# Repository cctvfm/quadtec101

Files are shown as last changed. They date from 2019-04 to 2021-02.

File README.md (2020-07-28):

# quadtec101
A Quad Panning Oscillator designed for the Neuztec 4 Festival

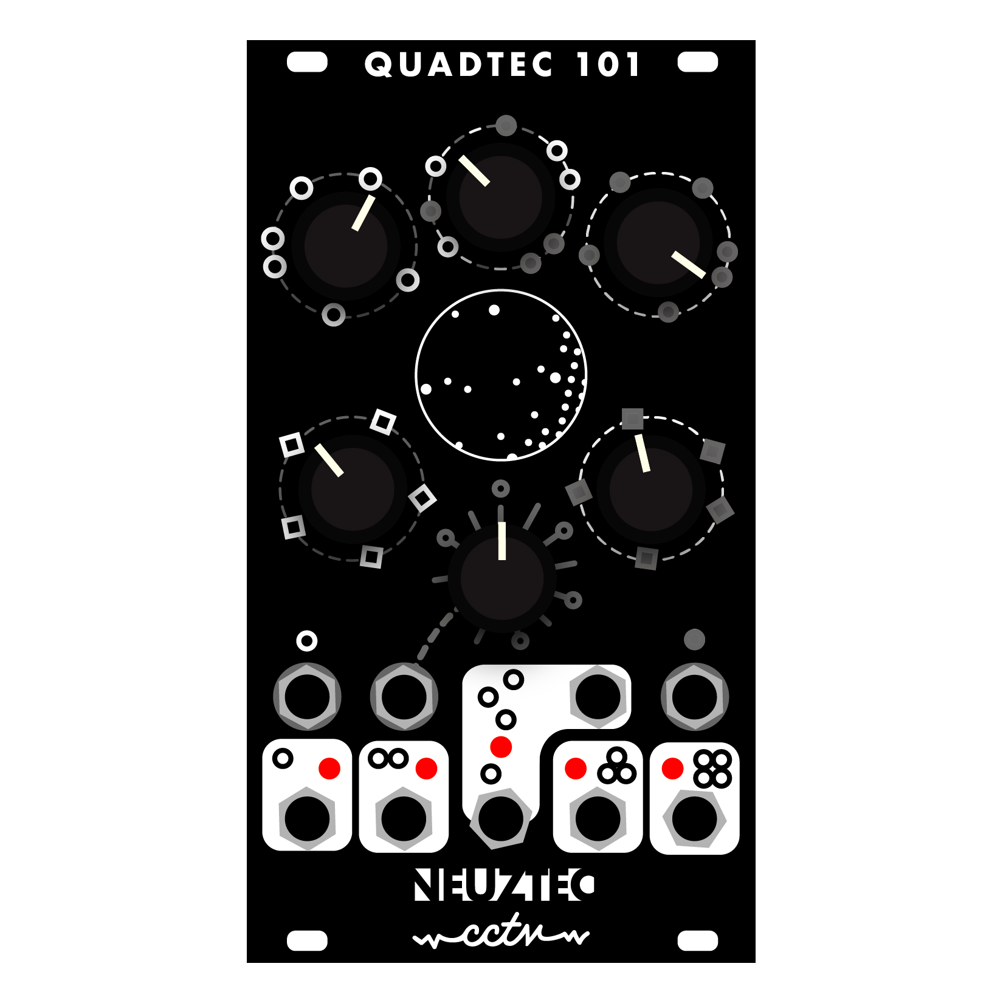
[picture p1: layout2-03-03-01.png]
QUADTEC-101 Render


More info here: [cctv.fm](https://www.cctv.fm/product-page/quadtec-101)

Sign up here: [Neuzlab](http://www.neuztec.ca/neuzlab/)

>QUADTEC-101 A MUSICAL INSTRUMENT FROM THE FUTURE.

>THE GARDEN CITY ELECTRONIC MUSIC COMMUNITY CREATED A TIMEMACHINE USING RARE TELSA BLUEPRINTS AND WENT INTO THE FUTURE TO GATHER DATA OF THE DAY; SEEKING OUT INSTRUMENTS FROM THE CREATIVE YOUTH OF THE FUTURE. UPON RETURNING TO 2019 THEY BROUGHT THOSE IDEAS TO FILIP PIETRUSZEWSKI TO RE-ENGINEER, DESIGN, AND REALIZE THIS FUTURISTIC INSTRUMENT USING MODERN AND ANTIIQUE TOOLS AT HIS MAD SCIENCE LAB AT CAPITAL CITY TRANSISTOR AND VALVE.

# Licensing

CC BY-NC-SA

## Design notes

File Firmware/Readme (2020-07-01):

Firmware is writting in C in MPLAB X IDE v 3.65. Some optimization is used, but it's using the free XC16 compiler.

.hex file can be uploaded through IPE and is ready to go. Make sure to select 'DSPIC30F3013' as the device type.

If you purchased a kit, the processor is pre-programmed and ready to go, no need to do any of this stuff.
V1.0 Released April 24th, 2019

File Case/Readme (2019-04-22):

Front and Sides are lasercut from 3mm Acrylic (plywood would work too)
Batteryholder is 3d printed at 1:1 scale.

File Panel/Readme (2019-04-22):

Panel is designed in Illustrator, and then imported into Eagle. BRD File is found here as well as gerber files where the layers have been 'mirrored' so the batch ID ends up on the bottom.

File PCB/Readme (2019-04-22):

This Folder Contains Eagle 9.12 SCH and BRD files, as well as gerbers ready to be sent out for manufacture.

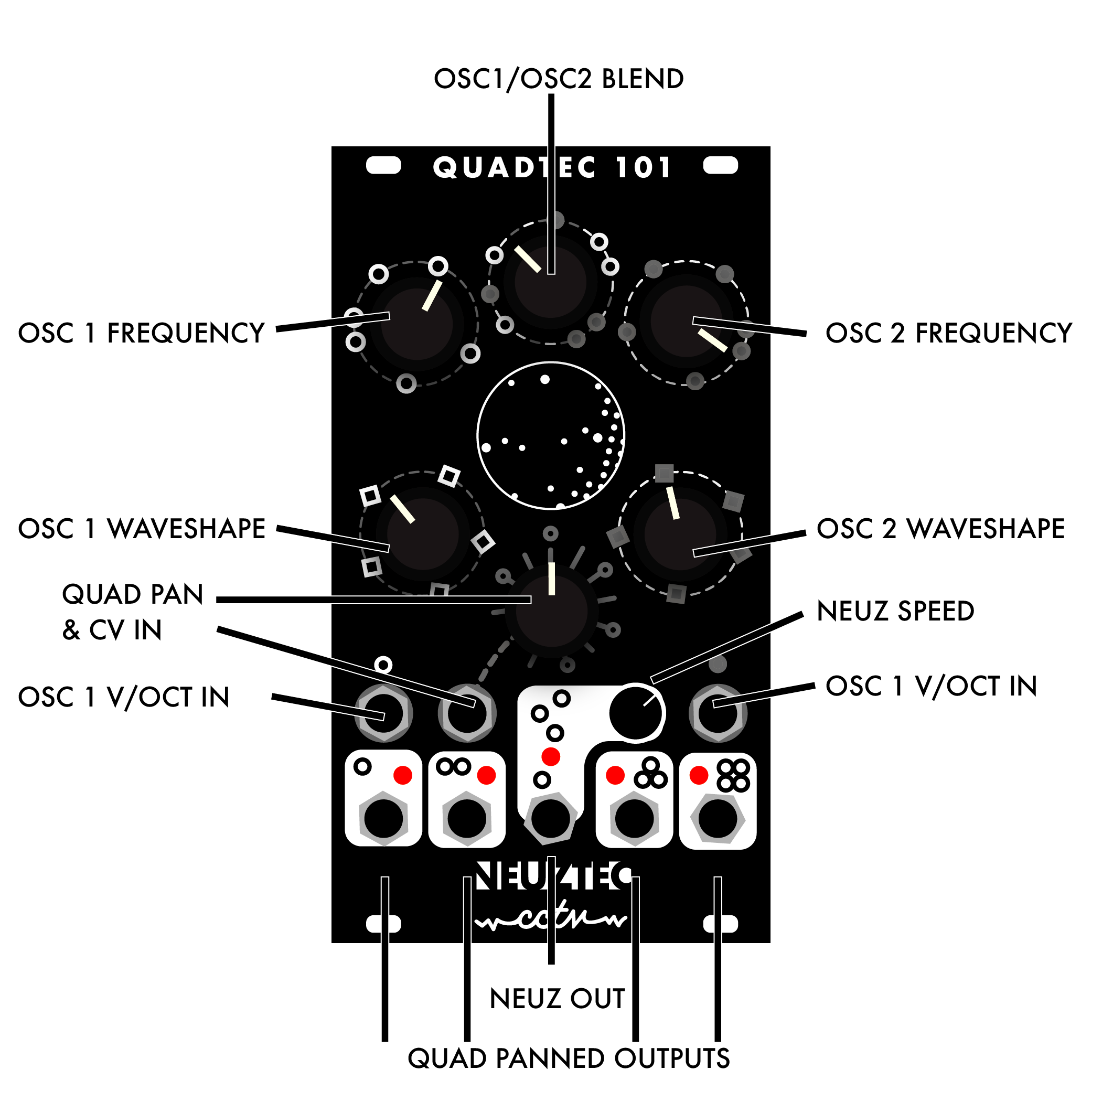
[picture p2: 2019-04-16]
quadtec--features-01.png

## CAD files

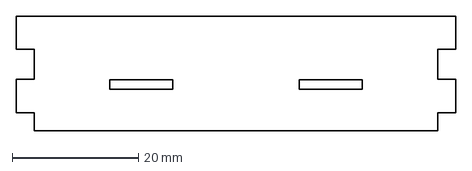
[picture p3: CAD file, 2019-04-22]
Case/front.dxf
69.7 x 18.2 mm

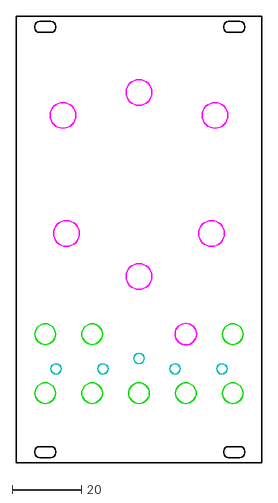
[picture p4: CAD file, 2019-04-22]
Panel/panel.dxf
70.8 x 128.5

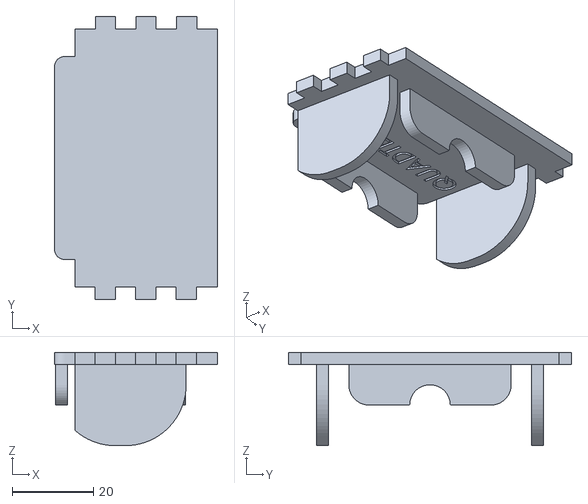
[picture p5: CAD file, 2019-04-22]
Case/BatteryHolder.stl
40.1 x 69.7 x 23.0

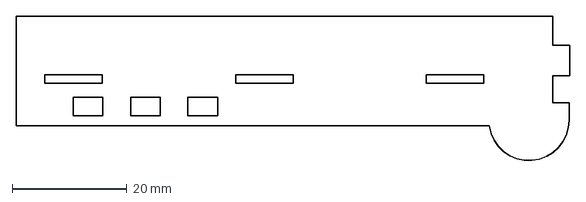
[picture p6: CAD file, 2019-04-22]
Case/side.dxf
96.5 x 25.4 mm

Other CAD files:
Firmware/Neuztech-1.X/dist/default/production/Neuztech-1.X.production.obj

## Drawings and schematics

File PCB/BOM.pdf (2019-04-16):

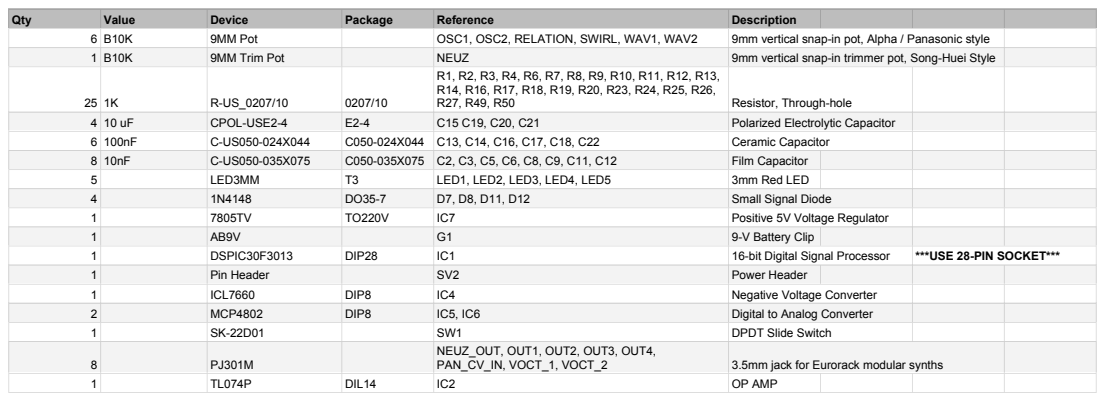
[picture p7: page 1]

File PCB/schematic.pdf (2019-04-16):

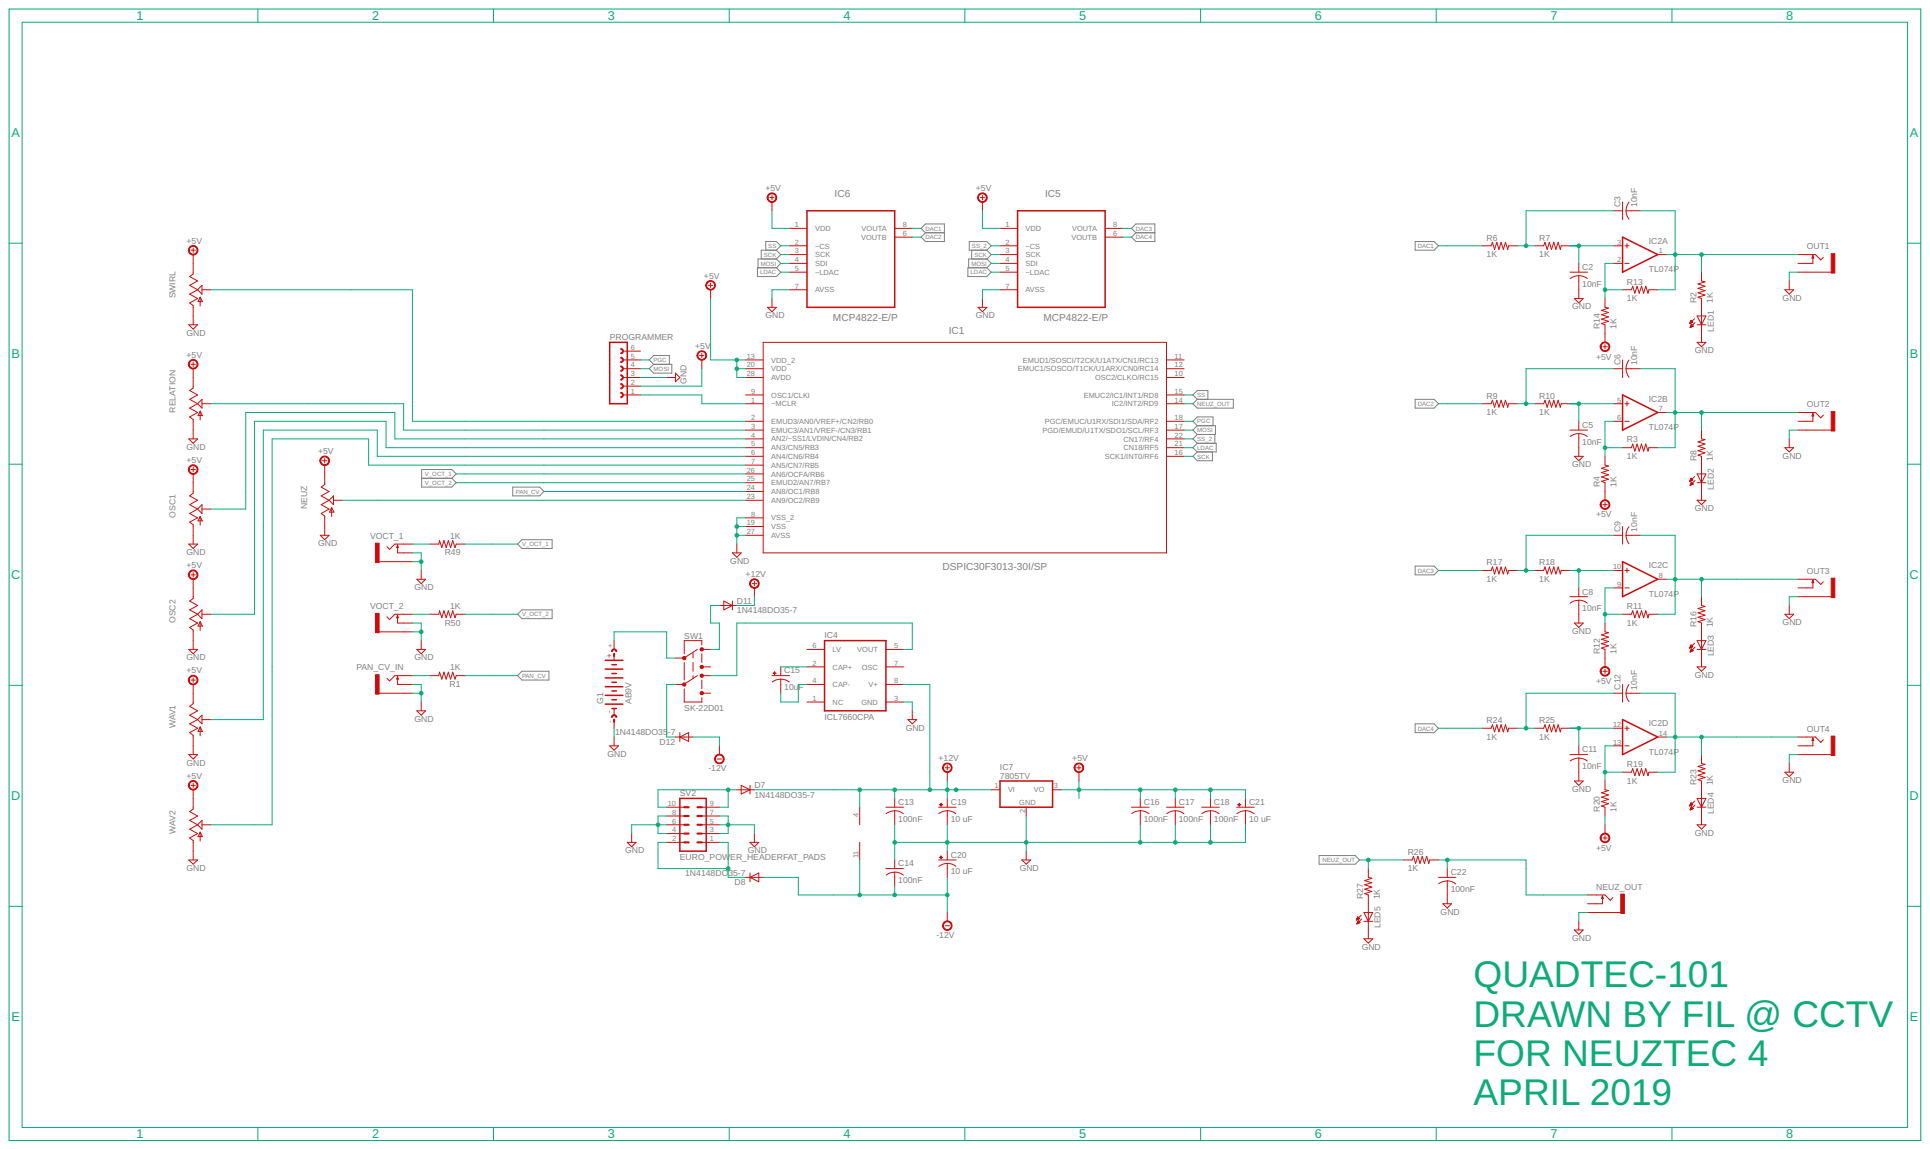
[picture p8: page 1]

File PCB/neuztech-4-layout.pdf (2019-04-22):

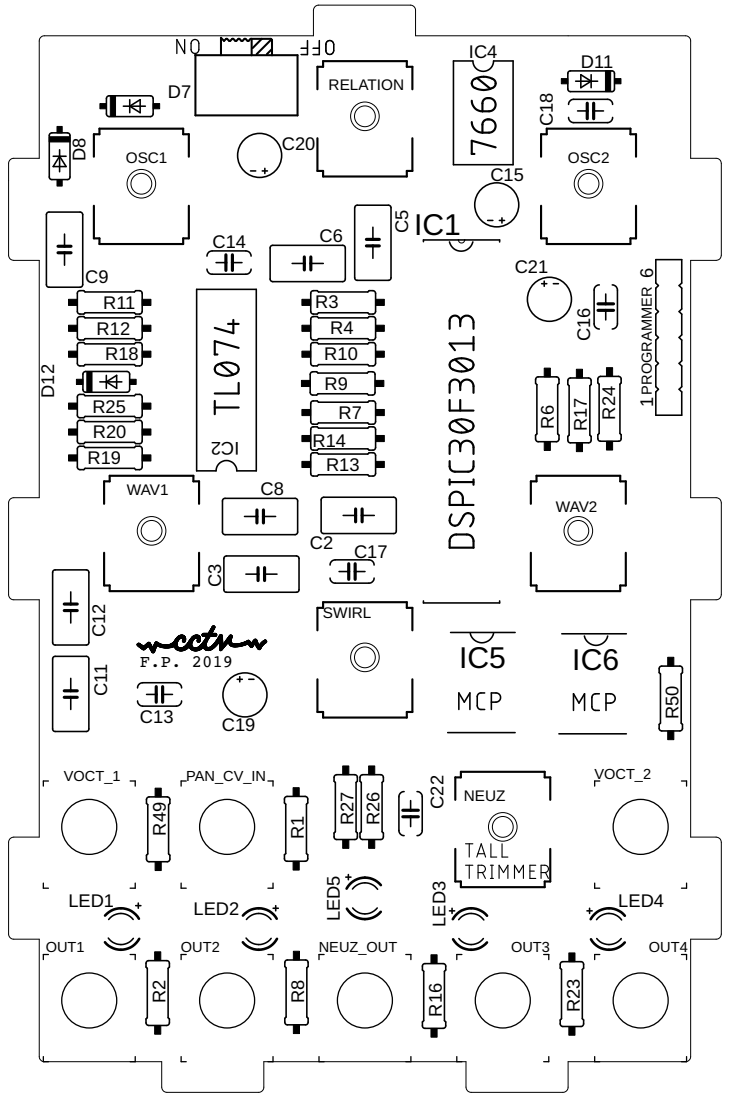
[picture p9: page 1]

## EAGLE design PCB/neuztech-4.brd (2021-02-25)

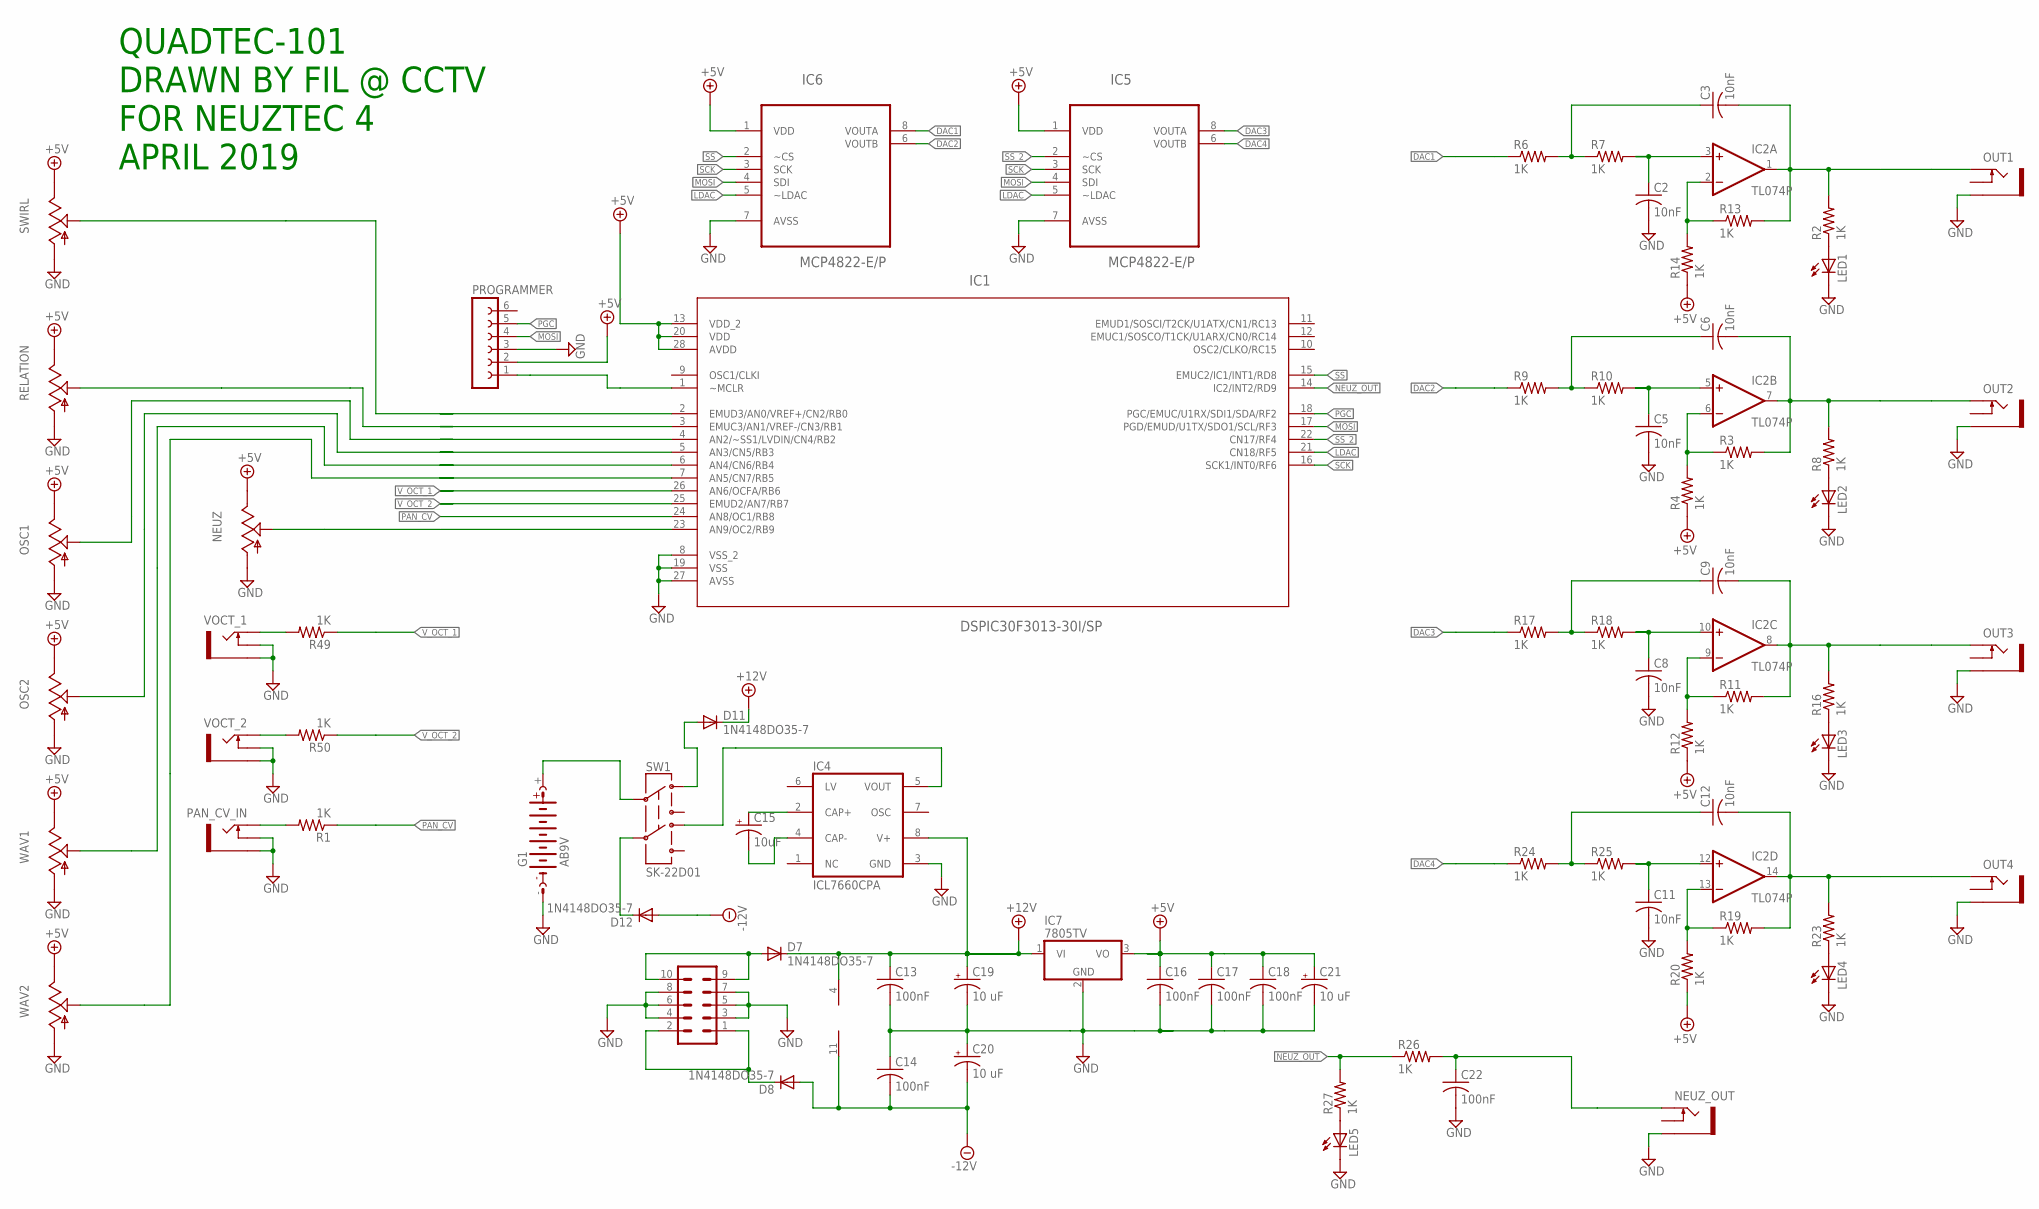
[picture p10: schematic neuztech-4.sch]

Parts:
C2, C3, C5, C6, C8, C9, C11, C12: 10nF; C050-035X075
C13, C14, C16, C17, C18, C22: 100nF; C050-024X044
C15: 10uF; E2-4
C19, C20, C21: 10 uF; E2-4
D7, D8, D11, D12: 1N4148DO35-7; DO35-7
G1: AB9V
IC1: DSPIC30F3013-30I/SP; DIP254P762X508-28
IC2: TL074P; DIL14
IC4: ICL7660CPA; DIL08
IC5, IC6: MCP4822-E/P; DIP254P762X432-8
IC7: 7805TV; TO220V
LED1, LED2, LED3, LED4, LED5: LED3MM
NEUZ: 9MM_SNAP-IN_POT_; 9MM_SNAP-IN_POT
NEUZ_OUT: THONKICONNNEW; WQP-PJ301M-12_JACK
OSC1, OSC2: 9MM_SNAP-IN_POT_; 9MM_SNAP-IN_POT
OUT1, OUT2, OUT3, OUT4: THONKICONNNEW; WQP-PJ301M-12_JACK
PAN_CV_IN: THONKICONNNEW; WQP-PJ301M-12_JACK
PROGRAMMER: FE06-1; FE06
R1, R2, R3, R4, R6, R7, R8, R9, R10, R11, R12, R13, R14, R16, R17, R18, R19, R20, R23, R24, R25, R26, R27, R49, R50: 1K; 0207/10
RELATION: 9MM_SNAP-IN_POT_; 9MM_SNAP-IN_POT
SV2: EURO_POWER_HEADERFAT_PADS; EURO_PWR_HEADER_FAT
SW1: SK-22D01; SK-22D01-MG
SWIRL: 9MM_SNAP-IN_POT_; 9MM_SNAP-IN_POT
VOCT_1, VOCT_2: THONKICONNNEW; WQP-PJ301M-12_JACK
WAV1, WAV2: 9MM_SNAP-IN_POT_; 9MM_SNAP-IN_POT

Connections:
+5V: C16.1, C17.1, C18.1, C21.+, IC1.13 (VDD_2), IC1.20 (VDD), IC1.28 (AVDD), IC5.1 (VDD), IC6.1 (VDD), IC7.3 (VO), NEUZ.3 (E), OSC1.3 (E), OSC2.3 (E), PROGRAMMER.2, R4.1, R12.1, R14.1, R20.1, RELATION.3 (E), SWIRL.3 (E), WAV1.3 (E), WAV2.3 (E)
+12V: C13.1, C19.+, D7.C, D11.C, IC2.4 (V+), IC4.8 (V+), IC7.1 (VI)
-12V: C14.2, C20.-, D8.A, D12.A, IC2.11 (V-)
DAC1: IC6.8 (VOUTA), R6.1
DAC2: IC6.6 (VOUTB), R9.1
DAC3: IC5.8 (VOUTA), R17.1
DAC4: IC5.6 (VOUTB), R24.1
GND: C2.2, C5.2, C8.2, C11.2, C13.2, C14.1, C16.2, C17.2, C18.2, C19.-, C20.+, C21.-, C22.2, G1.-, IC1.8 (VSS_2), IC1.19 (VSS), IC1.27 (AVSS), IC4.3 (GND), IC5.7 (AVSS), IC6.7 (AVSS), IC7.2 (GND), LED1.K (C), LED2.K (C), LED3.K (C), LED4.K (C), LED5.K (C), NEUZ.1 (A), NEUZ_OUT.P$3_SLEEVE (SLEEVE), OSC1.1 (A), OSC2.1 (A), OUT1.P$3_SLEEVE (SLEEVE), OUT2.P$3_SLEEVE (SLEEVE), OUT3.P$3_SLEEVE (SLEEVE), OUT4.P$3_SLEEVE (SLEEVE), PAN_CV_IN.P$2_SWITCH (SWITCH), PAN_CV_IN.P$3_SLEEVE (SLEEVE), PROGRAMMER.3, RELATION.1 (A), SV2.3, SV2.4, SV2.5, SV2.6, SV2.7, SV2.8, SWIRL.1 (A), VOCT_1.P$2_SWITCH (SWITCH), VOCT_1.P$3_SLEEVE (SLEEVE), VOCT_2.P$2_SWITCH (SWITCH), VOCT_2.P$3_SLEEVE (SLEEVE), WAV1.1 (A), WAV2.1 (A)
LDAC: IC1.21 (CN18/RF5), IC5.5 (~LDAC), IC6.5 (~LDAC)
MOSI: IC1.17 (PGD/EMUD/U1TX/SDO1/SCL/RF3), IC5.4 (SDI), IC6.4 (SDI), PROGRAMMER.4
unnamed: PAN_CV_IN.P$1_TIP (TIP), R1.2
unnamed: IC1.1 (~MCLR), PROGRAMMER.1
unnamed: C3.2, IC2.1 (OUT), OUT1.P$1_TIP (TIP), R2.2, R13.2
unnamed: LED1.A, R2.1
unnamed: C6.2, IC2.7 (OUT), OUT2.P$1_TIP (TIP), R3.2, R8.2
unnamed: IC2.6 (-IN), R3.1, R4.2
unnamed: C5.1, IC2.5 (+IN), R10.2
unnamed: C3.1, R6.2, R7.1
unnamed: LED2.A, R8.1
unnamed: C6.1, R9.2, R10.1
unnamed: D8.C, SV2.1, SV2.2
unnamed: C9.2, IC2.8 (OUT), OUT3.P$1_TIP (TIP), R11.2, R16.2
unnamed: IC2.9 (-IN), R11.1, R12.2
unnamed: C8.1, IC2.10 (+IN), R18.2
unnamed: LED3.A, R16.1
unnamed: IC2.2 (-IN), R13.1, R14.2
unnamed: C9.1, R17.2, R18.1
unnamed: D7.A, SV2.9, SV2.10
unnamed: C12.2, IC2.14 (OUT), OUT4.P$1_TIP (TIP), R19.2, R23.2
unnamed: IC2.13 (-IN), R19.1, R20.2
unnamed: C11.1, IC2.12 (+IN), R25.2
unnamed: C2.1, IC2.3 (+IN), R7.2
unnamed: LED4.A, R23.1
unnamed: C12.1, R24.2, R25.1
unnamed: LED5.A, R27.1
unnamed: C15.+, IC4.2 (CAP+)
unnamed: C22.1, NEUZ_OUT.P$1_TIP (TIP), R26.2
unnamed: C15.-, IC4.4 (CAP-)
unnamed: IC4.5 (VOUT), SW1.NC2
unnamed: G1.+, SW1.C1 (C)
unnamed: D11.A, SW1.NC1 (NC)
unnamed: D12.C, SW1.C2
unnamed: IC1.3 (EMUC3/AN1/VREF-/CN3/RB1), RELATION.2 (S)
unnamed: IC1.4 (AN2/~SS1/LVDIN/CN4/RB2), OSC1.2 (S)
unnamed: IC1.5 (AN3/CN5/RB3), OSC2.2 (S)
unnamed: IC1.6 (AN4/CN6/RB4), WAV1.2 (S)
unnamed: IC1.7 (AN5/CN7/RB5), WAV2.2 (S)
unnamed: IC1.2 (EMUD3/AN0/VREF+/CN2/RB0), SWIRL.2 (S)
unnamed: R50.2, VOCT_2.P$1_TIP (TIP)
unnamed: R49.2, VOCT_1.P$1_TIP (TIP)
NEUZ_OUT: IC1.14 (IC2/INT2/RD9), R26.1, R27.2
NEUZ_POT: IC1.23 (AN9/OC2/RB9), NEUZ.2 (S)
PAN_CV: IC1.24 (AN8/OC1/RB8), R1.1
PGC: IC1.18 (PGC/EMUC/U1RX/SDI1/SDA/RF2), PROGRAMMER.5
SCK: IC1.16 (SCK1/INT0/RF6), IC5.3 (SCK), IC6.3 (SCK)
SS: IC1.15 (EMUC2/IC1/INT1/RD8), IC6.2 (~CS)
SS_2: IC1.22 (CN17/RF4), IC5.2 (~CS)
V_OCT_1: IC1.26 (AN6/OCFA/RB6), R49.1
V_OCT_2: IC1.25 (EMUD2/AN7/RB7), R50.1

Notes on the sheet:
QUADTEC-101 DRAWN BY FIL @ CCTV FOR NEUZTEC 4 APRIL 2019

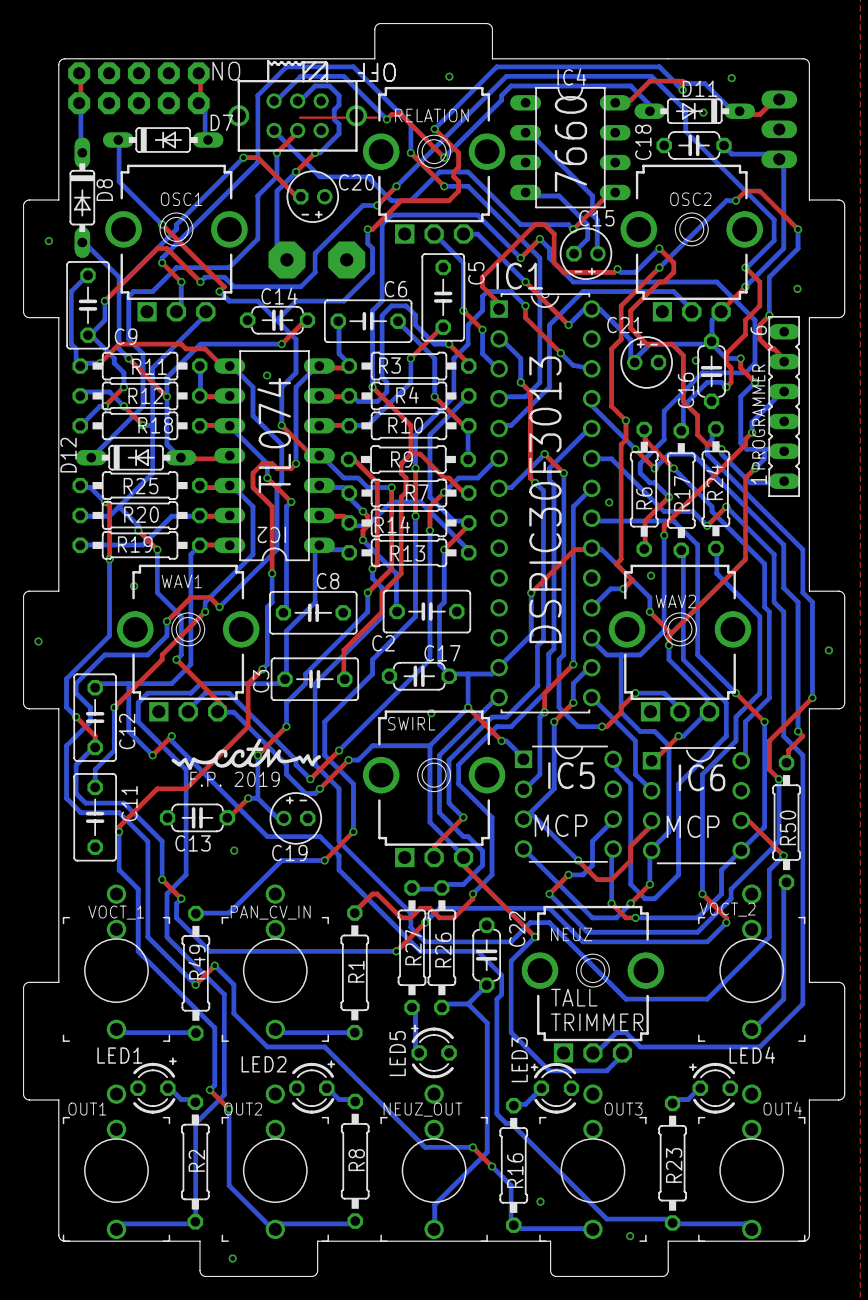
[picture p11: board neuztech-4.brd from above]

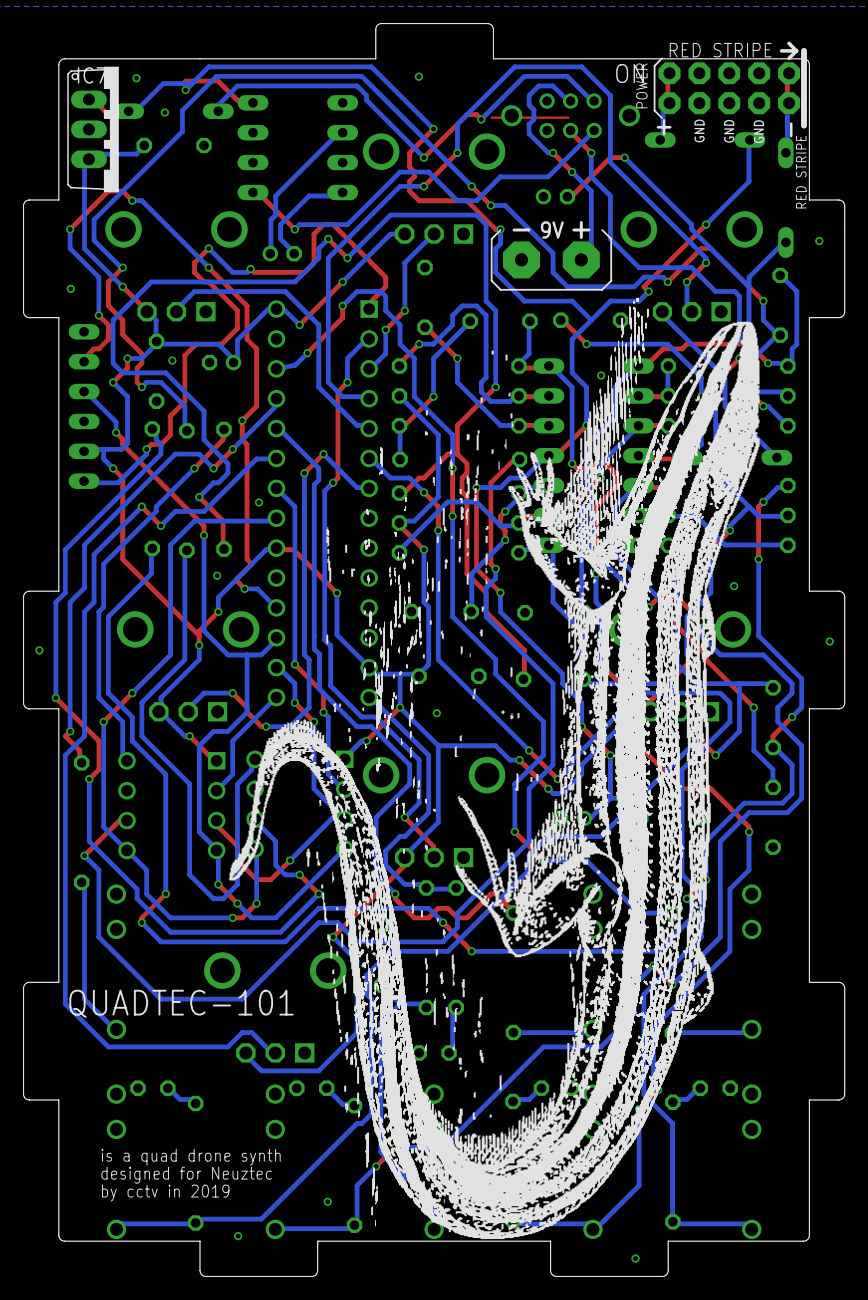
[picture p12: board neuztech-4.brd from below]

Board: 2 copper layers, 69.8 x 106.5 mm, 77 parts (4 on the bottom side), 59 nets.

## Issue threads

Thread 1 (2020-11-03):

Capacitor C22

bertrandmc, 2020-11-03:
The yellow build guide indicates that the 100nF Ceramic capacitors should be placed in C22 but the PCB symbol indicates C22 is a Film capacitor.

bertrandmc, 2020-11-03:
The yellow build guide indicates that the 100nF Ceramic capacitors should be placed in C22 but the PCB symbol indicates C22 is a Film capacitor.

cctvfm, 2021-02-25:
Files have been updated, There's a few kits still floating around with the square footprint. Always go by the BOM, not the shapes on the PCB!

Closed 2021-02-25.

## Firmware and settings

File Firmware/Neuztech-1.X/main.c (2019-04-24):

/*
 * File:   main.c
 * Author: filip
 *
 * Created on February 5, 2019, 12:38 PM
 */

#define FOSC (120000000ULL)
#define FCY FOSC/2
#include <libpic30.h>
#include "main.h"
#include "waveforms.h"
#include <math.h>
#include <dsp.h>


#define AIN TRISBbits.TRISB0

#define NEUZOUT LATDbits.LATD9

#define TWELVEBITMODE   //change in waveforms.h too!

//#define EIGHTBITMODE


#define SWIRL_CHANNEL       0b000
#define RELATION_CHANNEL    0b001
#define OSC1_CHANNEL        0b010
#define OSC2_CHANNEL        0b011
#define WAV1_CHANNEL        0b100
#define WAV2_CHANNEL        0b101
#define OSC1CV_CHANNEL      0b110  
#define OSC2CV_CHANNEL      0b111
#define ADCSAMPLES 10   //number of samples to be taken and averaged
                        //higher number means less jitter, but longer response rate

#define _XTAL_FREQ 120000000

#define SAMPLERATE 30000
#define TIMER1_RELOAD 750   //40KHz sample rate tested //750 for 40k, 1000 for 30k
#define HZPHASOR    108420     //108420 for 40K tested 144560 for 30k untested
#define LFOPHASORSCALE  100 //must be much slower than the hz phasor
                            //multiply by 4095/2 to get max swirl speed, about 2Hz? maybe too fast
                            //untested

//#define F0 16.35 //lowest possible note, all others are calculated from this one - Low C
#define F0 14 //make it a nice integer, should still be able to tune?
#define A 1.059463094   //power factor for semitones to frequency conversion
#define SINE 1
#define TRI 2
#define SQUARE 3

unsigned long int phaseaccumulator=0;
unsigned long int phaseaccumulator2 = 0;
unsigned long int phaseaccumulator3 = 0;
unsigned long int phaseaccumulator4 = 0;

unsigned long int lfoaccumulator=0;

unsigned int swirler[4];

unsigned long int phasor1;
unsigned long int phasor2;

unsigned long int lfophasor = LFOPHASORSCALE*100;
unsigned char lfodirection = 0;
#define NONE 0
#define LEFT 1
#define RIGHT 2

unsigned char VCAMODE=0;
#define OFF 0
#define ON 1
unsigned int waveshape1;
unsigned int waveshape2;
int waveshape1samples[ADCSAMPLES];

unsigned int relation = 0;

unsigned int SwirlH,SwirlL;
unsigned int AnalogInputs[10]={0,0,0,0,0,0,0,0,0,0};
unsigned int LastAnalogInputs[10]={0xFFFF,0xFFFF,0xFFFF,0xFFFF,0xFFFF,0xFFFF,0xFFFF,0xFFFF,0xFFFF,0xFFFF};
unsigned char currentMUXChannel = 0;
unsigned long int counter=0;
unsigned long int samplecounter = 0;
unsigned long int setpoint = 1000;


#define currentSWIRL AnalogInputs[0]
#define currentRELATION AnalogInputs[1]
#define currentOSC1 AnalogInputs[2]
#define currentOSC2 AnalogInputs[3]
#define currentWAV1 AnalogInputs[4]
#define currentWAV2 AnalogInputs[5]
#define currentVOCT1 AnalogInputs[6]
#define currentVOCT2 AnalogInputs[7]
#define currentPANCV AnalogInputs[8]
#define currentNEUZ  AnalogInputs[9]

#define lastSWIRL LastAnalogInputs[0]
#define lastRELATION LastAnalogInputs[1]
#define lastOSC1 LastAnalogInputs[2]
#define lastOSC2 LastAnalogInputs[3]
#define lastWAV1 LastAnalogInputs[4]
#define lastWAV2 LastAnalogInputs[5]
#define lastVOCT1 LastAnalogInputs[6]
#define lastVOCT2 LastAnalogInputs[7]
#define lastPANCV LastAnalogInputs[8]
#define lastNEUZ  LastAnalogInputs[9]


unsigned int DACA,DACB,DACC,DACD;



//Interrupts 40,000 times per second.
void __attribute__((__interrupt__,__auto_psv__)) __attribute__((optimize("-O0")))  _T1Interrupt(void)
{

   
    
    signed int currentsample;
    unsigned int rando;
    
    

    
    if (IFS0bits.T1IF == 1)   //synth engine routine
    {
        IEC0bits.T1IE = 0;
        WriteDac(1,DACA,DACB);  //write the last calculated sample so we're staying true to our sample rate
        WriteDac(2,DACC,DACD);
        
        PR1 = TIMER1_RELOAD;
        IFS0bits.T1IF = 0;          //Have these three lines at end for function forgiveness,
        IEC0bits.T1IE = 1;          //put them at the start for sample rate accuracy
         
        samplecounter++;
         
        phaseaccumulator = phaseaccumulator + phasor1;
        phaseaccumulator2= phaseaccumulator2 + phasor2;

        if(lfodirection == LEFT)
            lfoaccumulator = lfoaccumulator - lfophasor;    //for the swirler
        else if(lfodirection == RIGHT)
            lfoaccumulator = lfoaccumulator + lfophasor;    //for the swirler
        
        //currentsample = getSample(phaseaccumulator>>22,waveshape1);
        //currentsample = currentsample + getSample(phaseaccumulator3>>22,waveshape2);
        
        //currentsample = currentsample /2;
        
        currentsample = Scale(getSample(phaseaccumulator>>22,waveshape1),1023-relation) 
                    // +getSample(phaseaccumulator2>>22,waveshape1)
                       +Scale(getSample(phaseaccumulator2>>22,waveshape2),relation)
                    // +getSample(phaseaccumulator3>>22,waveshape2)
                        ;
        
        if(lfodirection != NONE)
        {
            DACA = Scale(currentsample,swirler[0]);
            DACB = Scale(currentsample,swirler[1]);
            DACC = Scale(currentsample,swirler[2]);
            DACD = Scale(currentsample,swirler[3]);
        }
        else if(VCAMODE == ON)
        {
            DACA = Scale(currentsample,currentPANCV>>2);
            DACB = Scale(currentsample,currentPANCV>>2);
            DACC = Scale(currentsample,currentPANCV>>2);
            DACD = Scale(currentsample,currentPANCV>>2);
        }
        else
        {
            DACA = currentsample;
            DACB = currentsample;
            DACC = currentsample;
            DACD = currentsample;
        }
        //DACC = getSample(phaseaccumulator3>>22,waveshape2);
        //DACD = DACC;
        //DACB = getSample(phaseaccumulator>>22,waveshape1);
        //DACA = DACA + DACB;
        //DACA = DACA>>1;
        //DACB=DACA;
        //to do, when adding these two waveforms, weird stuff happens.
        //edit, i think it's because of phasor discrepancy, if the interval is 0, phasors need to be identical.

        
        
        

        
        if(counter > setpoint)
        {
            rando= rand() % 2;
            if(rando==1)
                NEUZOUT = 1;
            else
                NEUZOUT = 0;

            counter = 0;
        }

        
        counter++;
        
        /*
        PR1 = TIMER1_RELOAD;
        IFS0bits.T1IF = 0;          //Have these three lines at end for function forgiveness,
        IEC0bits.T1IE = 1;          //put them at the start for sample rate accuracy
        */
        
    }
    

            
            
}


int __attribute__((optimize("-O0"))) main(void) {
    
    chipconfig();
    unsigned int fun;
    unsigned char x;

    unsigned int y;
    unsigned int totalADC;
    unsigned int testswirler;

    unsigned int loopcounter = 0;
    unsigned long int templong;

    unsigned int calculatedSWIRL;
    unsigned int VCACOUNTER = 0;
    unsigned long int VCAENTRY = 0;
    unsigned char VCAENTRYFLAG = 0;
    
    
    //grab all the inputs real quick first.
    for(x=0;x<=9;x++)
    {
        AnalogInputs[loopcounter]=ReadAIN(loopcounter);
    }
    
    T1CONbits.TON = 1;  //start sampling timer
    

    fun = 0;    //no more fun
    
    while(1)
    {
           

        AnalogInputs[loopcounter]=ReadAIN(loopcounter);
        
        loopcounter++;
        
        if(loopcounter>9)
            loopcounter = 0;
        
        
        
        //compute 4 scale factors for swirler
        y=lfoaccumulator>>22;
        for(x=0;x<4;x++)
        {
            if(triwave(y)>0)
            {   testswirler = triwave(y);
                testswirler = testswirler >> 1;
                
                swirler[x]=testswirler;
            }
            else
                swirler[x] = 0;
            
            
            y=y+256;
            if(y>1023)
                y=y-1023;
        }

        #define UPPERVCALIMIT 2207
        #define LOWERVCALIMIT 1887

        #define VCACOUNTLIMIT 2000
        #define VCASAMPLEDELAY 40000
        if(currentSWIRL != lastSWIRL || currentPANCV != lastPANCV)
        {

            
            
            //max is 4095
            //mid is 2047
            if(currentSWIRL<=UPPERVCALIMIT && currentSWIRL >= LOWERVCALIMIT)    //we're in VCA MODE!
            {
                
                if(VCAENTRYFLAG == 0 )
                {
                    VCAENTRYFLAG = 1;
                    VCAENTRY = samplecounter;

                
                }

            }
            else
            {
                VCAENTRYFLAG = 0;
            }
            if(VCAENTRYFLAG != 2)
            {
                
                
                calculatedSWIRL = currentSWIRL + currentPANCV;
                calculatedSWIRL = calculatedSWIRL;
 
                
                
                if(calculatedSWIRL>2047)
                {
                    templong = (calculatedSWIRL -2047);   //0-2000 slowest to fastest good
                    templong = templong * LFOPHASORSCALE;
                    lfodirection = LEFT;
                    lfophasor = templong;

                    VCAMODE = OFF;
                }
                else if(calculatedSWIRL<=2047)
                {
                    templong = 2048 - calculatedSWIRL;    //0-2000 fastest to slowest good

                    templong = templong * LFOPHASORSCALE;
                    lfodirection = RIGHT;
                    lfophasor = templong;

                    VCAMODE = OFF;
                }
                    
                
                
            }

            

 
            lastSWIRL = currentSWIRL;
            lastPANCV = currentPANCV;
        }
        if (VCAENTRYFLAG == 1)
        {

            if((samplecounter - VCAENTRY)>VCASAMPLEDELAY)
            {
                VCAENTRYFLAG = 2;
                lfodirection = NONE;
                lfophasor = 0;
            }

        }
         
        if(lfodirection == NONE)
        {
           if(currentPANCV > 300)
           VCAMODE = ON;
        }
        
        if((currentVOCT1 != lastVOCT1) || (currentOSC1 != lastOSC1))
        {
            
            totalADC = currentOSC1 + currentVOCT1;
            
            phasor1 = IntToFreq(totalADC);
            
            
            lastVOCT1 = currentVOCT1;
            lastOSC1 = currentOSC1;
            
        }
        
        if(currentRELATION != lastRELATION)
        {

            
            relation = currentRELATION/4;
            lastRELATION = currentRELATION;
             
        }
        
        if((currentVOCT2 != lastVOCT2) || (currentOSC2 != lastOSC2))
        {
            totalADC = currentOSC2 + currentVOCT2;
            
            phasor2 = IntToFreq(totalADC);
           
            lastVOCT2 = currentVOCT2;
            lastOSC2 = currentOSC2;
            
            
            lastRELATION = currentRELATION;
        }

        waveshape1=currentWAV1;
        waveshape2=currentWAV2;
        
        setpoint = 0xFFF-currentNEUZ;

      
        }
        
   
    

    
    return 0;
}

unsigned long int __attribute__((optimize("-O0"))) IntToFreq (unsigned int value)
{
    unsigned int octave,pitch;
    unsigned long frequencyint;

    
    octave = value / 819;    //octave now contains the octave above the lowest
    pitch = value % 819;     //pitch now contains the value between 0 and 819 which is the range between octaves
    //819 refers to 1V at the 0-4095 / 0-5V scale
    
    //what we're doing is F0*a^(semitone) * HZPHASOR
    //the exponent part is calculated with a lookup table to avoid the slow powf function
    //to reduce size, we're only saving a single octave of the exponent part, then multiplying by the number of octaves
    
    frequencyint = voctscale[(pitch>>1)];
    //frequencyint = frequencyint * HZPHASOR;
    //frequencyint = frequencyint >> 16;    //won't fit in 32 bit
    frequencyint = (frequencyint>>1)*HZPHASOR;   //lose an lsb this way.
    frequencyint = frequencyint >> 15;
    frequencyint = frequencyint + HZPHASOR; //fixed point means we lose the original 1.xxx so we add it back

    frequencyint = frequencyint * octavemultipler[octave];   //multiply by powers of 2, eg 1, 2, 4, 8 - saved in a lookup table
    return (frequencyint * F0);
    
}
unsigned int ReadAIN (unsigned char channel)
{
    ADCHS=channel&0x0F;
    ADPCFG=~((unsigned int)1<<channel);
    ADCON1 = 0x00E0;
    ADCON2 = 0x0000; //channel 0
    //ADCON3 = 0X1F3F;
    ADCON3 = 0x0808;
    
    
    
    ADCSSL=0;
    
    ADCON1bits.ADON = 1;
    ADCON1bits.SAMP = 1;
    
    while(!ADCON1bits.DONE);
    return ADCBUF0;
}


void chipconfig (void)
{
    //code protection sequence
    OSCCONL = 0x46;
    OSCCONL = 0x57;
    OSCCONL = 0x00;//real osccon value here
    OSCCONH = 0x78;
    OSCCONH = 0x9A;
    OSCCONH = 0x03;//real oscconh here
    //write oscconh here
    
    while(OSCCONbits.LOCK ==0);
    
    
    U1MODEbits.UARTEN=0;

    T1CON = 0;
    TMR1 = 0;

    IPC0bits.T1IP = 1;
    IFS0bits.T1IF = 0;
    IEC0bits.T1IE = 1;
    T1CON = 0;
    INTCON1 = 0x8000;
    INTCON2 = 0x0000;

    
    AIN = 1;

    
    //SPI SETUP
    
    TRISFbits.TRISF6 = 0;   //sck
    TRISFbits.TRISF3 = 0;   //sdo
    TRISFbits.TRISF4 = 0;   //cs2
    TRISDbits.TRISD8 = 0;   //cs1
    TRISFbits.TRISF5 = 0;  //ldac

    
    TRISDbits.TRISD9 = 0;   //Neuz out
    
    //AIN 0-9
    TRISBbits.TRISB0 = 1;
    TRISBbits.TRISB1 = 1;
    TRISBbits.TRISB2 = 1;
    TRISBbits.TRISB3 = 1;
    TRISBbits.TRISB4 = 1;
    TRISBbits.TRISB5 = 1;
    TRISBbits.TRISB6 = 1;
    TRISBbits.TRISB7 = 1;
    TRISBbits.TRISB8 = 1;
    TRISBbits.TRISB9 = 1;
    
    #define CS1 LATDbits.LATD8
    #define CS2 LATFbits.LATF4
    #define LDAC LATFbits.LATF5
    LDAC = 1;
    CS1 = 1;
    CS2 = 1;
    SPI1STATbits.SPIROV = 0;
    SPI1CON = 0x003F;
    SPI1CONbits.CKE = 0;
    SPI1CONbits.CKP = 1;
    //SPI1CONbits.MODE16 = 1;
    SPI1STATbits.SPIEN = 1;
    
    //Sample Rate Timer setup (timer1)
    
    
    
}

void __attribute__((optimize("-O0"))) PutSPIByte (unsigned char data)
{
    unsigned char temp;    
    temp = SPI1BUF;
    Nop();
    SPI1BUF = data;
    while(SPI1STATbits.SPITBF ==0);
}

void __attribute__((optimize("-O0"))) PutSPIByte16 (unsigned int data)
{
    unsigned int temp;    
    temp = SPI1BUF;
    Nop();
    SPI1BUF = data;
    while(SPI1STATbits.SPITBF ==0);
}

void __attribute__((optimize("-O0"))) WriteDac(unsigned char DAC,signed int data1, signed int data2)
{
    data1=data1+2047;
    data2=data2+2047;
    
    if(data1 < 0)
        data1=0;
    if(data2 < 0)
        data2=0;
    #define SPIdelay() Nop(); Nop(); Nop();
    unsigned char highbyte,lowbyte;
    //0001 is high gain
    //0011 is low gain
    lowbyte = data1 & 0xff;
    highbyte = (data1 >> 8);
    highbyte = highbyte | 0b00010000;

    if(DAC == 1)
        CS1 = 0;
    else
        CS2 = 0;
    Nop();
    PutSPIByte (highbyte);
    PutSPIByte(lowbyte);

    Nop();
    if(DAC == 1)
        CS1 = 1;
    else
        CS2 = 1;
    
    SPIdelay();
    
    //Send the B
    lowbyte = data2 & 0xff;
    highbyte = (data2 >> 8);
    highbyte = highbyte | 0b10010000;
    if(DAC == 1)
        CS1 = 0;
    else
        CS2 = 0;
    Nop();
    PutSPIByte (highbyte);
    PutSPIByte(lowbyte);
    Nop();
    CS1 = 1;
    CS2 = 1;

    LDAC = 0;
    SPIdelay();
    LDAC = 1;
    
    
    
}

signed int getSample (unsigned int index, unsigned int blend)
{
    
    signed  int sample=0;   //if you change this to long int, it stops working
    //sine, tri, evenangle,eventooth,saw,square -in order of harmonics
    //for 6 waveforms, need 20 point steps (divide by two) - todo add more waveforms
    #define BLENDSTEPS 16   //works with 10, not with 20, works with 15
    #define NUM_WAVES 9
    #define SCALER (4095/((NUM_WAVES-1)*BLENDSTEPS))
    unsigned int blender;
    blender = blend;
    //blend is max 4095
    blender = blender/SCALER;
    //blender needs to be max (num_waves-1 * BLENDSTEPS)
        //blend contains a value between 0 and 50    
    if(blender>((NUM_WAVES-1)*BLENDSTEPS))
        blender=(NUM_WAVES-1)*BLENDSTEPS;
    else if (blender<0)
        blender = 0;
    
    
    signed  int sample2;  //you get half sample rate for some reason...

    /*
    0 = pure sinewave
     * 0-10 blend of sine to tri
     * 10 = pure tri
     * 10-20 = blend of tri and evenangle
     * 20 = pure evenangle
     * 20-30 = blend of evenangle and eventooth
     * 30 = pure eventooth
     * 30-40 = blend of eventooth and saw
     * 40 = pure saw
     * 40-50 = blend of saw and square
     * 50 = pure square     
     */
    
    if(blender % BLENDSTEPS == 0)
    {
        switch(blender){
            case 0:
                sample=triwave(index);
                break;
            case BLENDSTEPS:
                sample = evenangle[index];
                break;
            case (BLENDSTEPS*2):
                sample = eventooth[index];
                break;
                
            case BLENDSTEPS*3:
                sample = cellowave[index];
                break;    
                
            case BLENDSTEPS*4:
                sample = sawwave(index);
                break;
            case BLENDSTEPS*5:
                sample = squarewave(index);
                break;
            case BLENDSTEPS*6:
                sample = vgamewave(index);
                break;
            case BLENDSTEPS*7:
                sample = pluckwave[index];
                break;
            case BLENDSTEPS*8:
                sample = fmwave[index];
                break;                
        }
    }
    else    //sample is not a pure wave, some mixing needs to be done
    {

        if(blender<(BLENDSTEPS))
        {

            sample = triwave(index);
            sample = __builtin_mulsu(sample,(BLENDSTEPS - blender));
            //sample = sample * (BLENDSTEPS-blender);
            sample2 = evenangle[index];
            sample2 = sample2 * (blender); 
            sample = sample+sample2;
            //for BLENDSTEPS == 16, >>4
            sample = sample>>4;
            
        }
        else if(blender<(BLENDSTEPS*2))
        {
            blender = blender-(BLENDSTEPS);
            sample = evenangle[index];
            sample = sample * (BLENDSTEPS-blender);
            sample2 = eventooth[index];
            sample2 = sample2 * (blender); 
            sample = sample + sample2;
            sample = sample>>4;
        }
        
        else if(blender<(BLENDSTEPS*3))
        {
            blender = blender-(BLENDSTEPS*2);
            sample = eventooth[index];
            sample = sample * (BLENDSTEPS-blender);
            sample2 = cellowave[index];
            sample2 = sample2 * (blender);   
            sample = sample+sample2;
            sample = sample>>4;            
            
        }            

        else if(blender<(BLENDSTEPS*4))
        {
            blender = blender-(BLENDSTEPS*3);
            sample = cellowave[index];
            sample = sample * (BLENDSTEPS-blender);
            sample2 = sawwave(index);
            sample2 = sample2 * (blender);   
            sample = sample+sample2;
            sample = sample>>4;            
            
        }        
        else if(blender<(BLENDSTEPS*5))
                
        {
            blender = blender-(BLENDSTEPS*4);
            sample = sawwave(index);
            sample = sample * (BLENDSTEPS-blender);
            sample2 = squarewave(index);
            sample2 = sample2 *(blender); 
            sample = sample+sample2;
            sample = sample>>4;            
        }
        
        else if(blender<(BLENDSTEPS*6))
                
        {
            blender = blender-(BLENDSTEPS*5);
            sample = squarewave(index);
            sample = sample * (BLENDSTEPS-blender);
            sample2 = vgamewave(index);
            sample2 = sample2 *(blender); 
            sample = sample+sample2;
            sample = sample>>4;            
        }
        
        else if(blender<(BLENDSTEPS*7))
                
        {
            blender = blender-(BLENDSTEPS*6);
            sample = vgamewave(index);
            sample = sample * (BLENDSTEPS-blender);
            sample2 = pluckwave[index];
            sample2 = sample2 *(blender); 
            sample = sample+sample2;
            sample = sample>>4;            
        }

        else if(blender<(BLENDSTEPS*8))
                
        {
            blender = blender-(BLENDSTEPS*7);
            sample = pluckwave[index];
            sample = sample * (BLENDSTEPS-blender);
            sample2 = fmwave[index];
            sample2 = sample2 *(blender); 
            sample = sample+sample2;
            sample = sample>>4;            
        }        
        else
        {
            sample = triwave(index);   //default value in case anything messes up
        }    
        
    }
        
    return sample;
}

signed int squarewave (unsigned int acc)
{
    if(acc<512)
        return 2047;
    else
        return -2047;
}
signed int sawwave (unsigned int acc)
{
    int value;
    value = 2047-(acc*4);

    return (unsigned)value;
}

signed int vgamewave (unsigned int acc)
{
    if(acc<200)
        return 0;
    else if(acc>849)
        return 0;
    else if(acc>549)
        return -32;
    else
        return (partialvgame[acc-200]);
}
signed int triwave (unsigned int acc)
{
    if(acc<=256)
    {
        return (acc*7);
    }
    else if(acc<=512)
    {
        acc=acc-256;
        acc = 256 - acc;
        return (acc*7);
    }
    else if(acc<=768)
    {
        acc = acc-512;
        return 0-(acc*7);
    }
    else
    {
        acc= acc-768;
        acc=256-acc;
        return 0-(acc*7);
    }
}
signed int getAverage(signed int * array,unsigned char length)
{
    signed long value=0;
    unsigned char x;
    for( x = 0; x < length; x++)
    {
        value = value+ *array;
        array++;
    }
    value = value/length;
    return (signed int)value;
}
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

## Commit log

2019-04-16 Uploaded schematics, gerbers, and BOM
    [NEUZPANEL.brd, neuztech-4.brd, neuztech-4.sch]
2019-04-22 Rearranged PCB Files
    [neuztech-4.brd, neuztech-4.sch]
